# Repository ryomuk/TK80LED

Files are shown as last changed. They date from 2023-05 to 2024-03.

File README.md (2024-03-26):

# TK80LED
TK-80互換機(ZK-80P)用LED表示盤(TK-80 flavor LED board for ZK-80P)

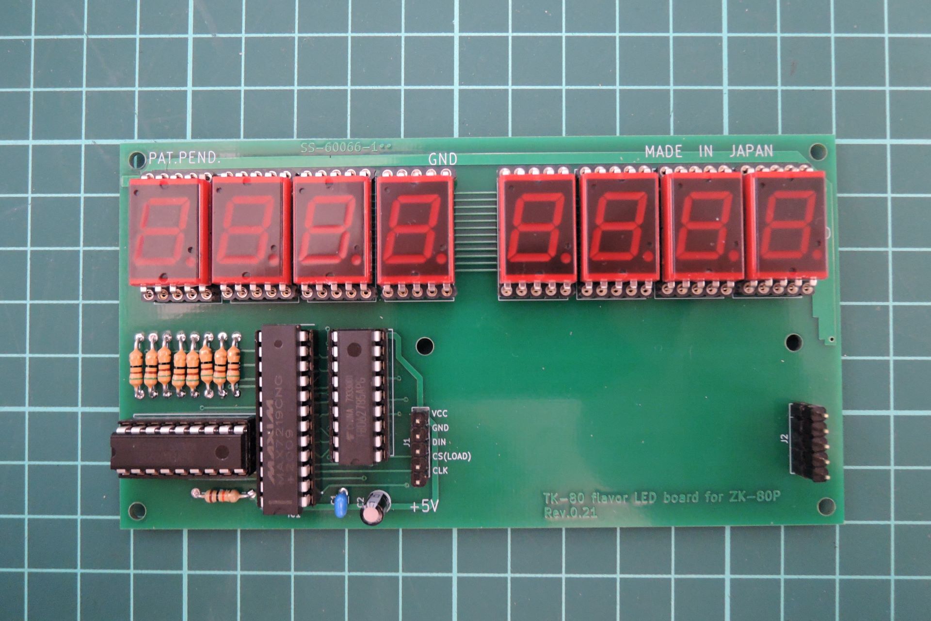
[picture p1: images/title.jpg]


## 概要
オレンジピコショップで売られているTK-80互換機(ZK-80 ポケット(ZK-80P))用の表示盤
「TK-80 flavor LED board for ZK-80P」です．

オリジナルのキットの表示がTK-80っぽくなかったので，SN713を使って本物っぽくしてみました．
ZK-80ポケット(ZK-80P)用です．ZK-80には対応していません．

私が勝手に作ったもので，ZK-80, ZK-80Pの作者様やピコソフト様とは無関係です．

## 基板
配線パターン，LED配置，シルクはかなり実機に似せたこだわりの作り(笑)になっています．
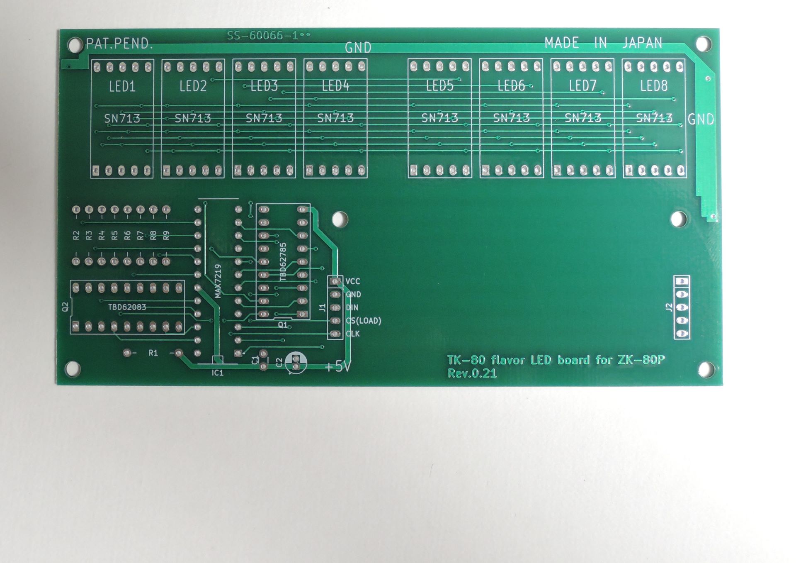
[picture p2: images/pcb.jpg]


## ファームウェア書き換えについて
ZK-80PはMAX7219の輝度の設定値が小さいので，そのままの設定でSN713を駆動するとかなり暗いです．
明るくするためには，ZK-80Pのファームウェアを書き換えが必要です．
ファームウェアの書き換えについては下記のブログをご参照下さい．

ファームウェア書き換え後
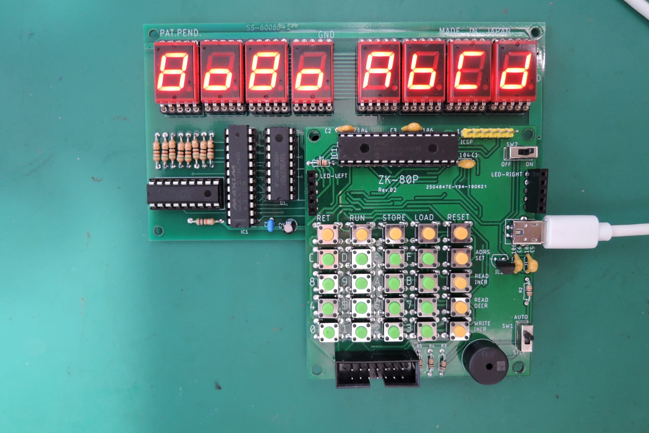
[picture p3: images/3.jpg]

実機との比較
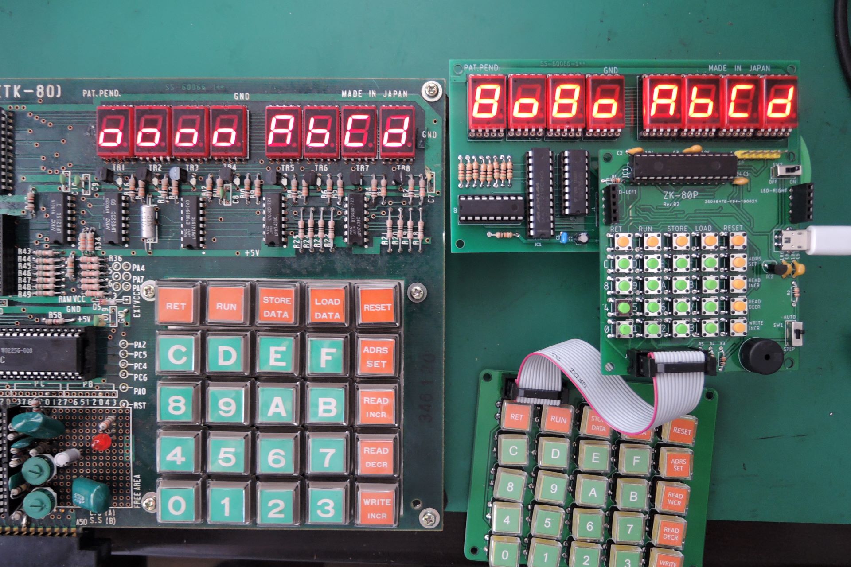
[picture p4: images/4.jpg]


ファームウェア書き換え前
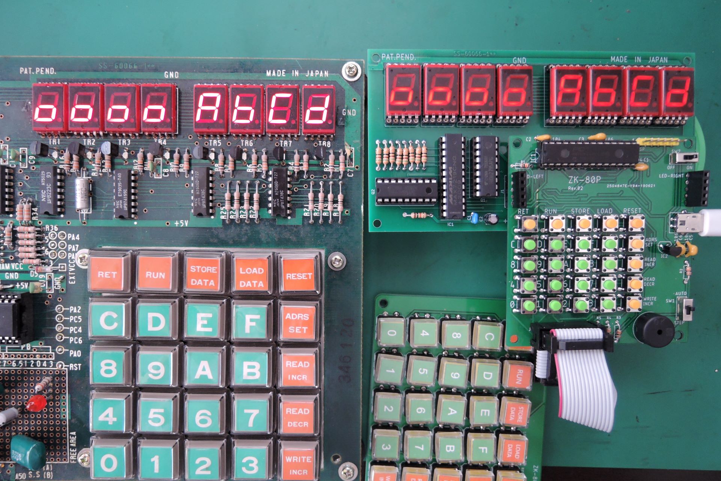
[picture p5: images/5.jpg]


## 関連ブログ
 - [ZK-80(TK-80互換機)のLED改装](https://blog.goo.ne.jp/tk-80/e/5548a42761d789a6131d8d7753d236a3)

## 免責事項
- 本機によってZK-80Pに不具合等が発生しても一切関知しません．

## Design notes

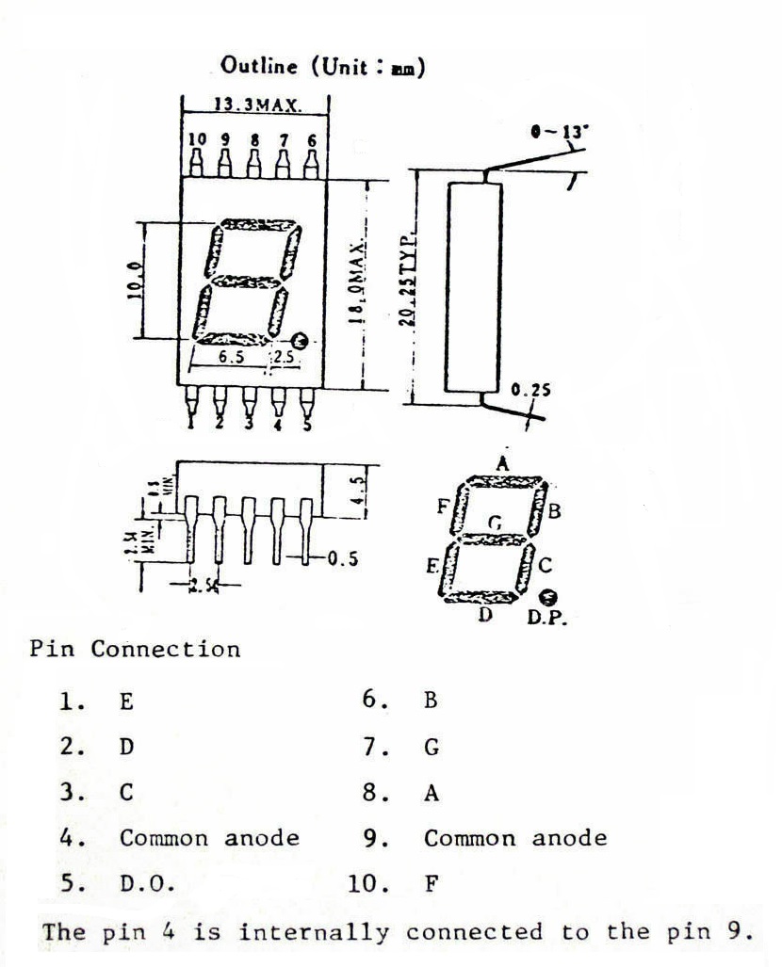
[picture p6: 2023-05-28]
hardware/rev0.21/SN713datasheet.jpg

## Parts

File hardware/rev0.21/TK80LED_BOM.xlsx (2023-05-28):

部品表
Item | Qty | Reference(s) | Value | 備考
1 | 1 | C1 | 0.1uF
2 | 1 | C2 | 10uF
3 | 1 | IC1 | MAX7219CNG
4 | 2 | J1, J2 | Conn_01x05 | ピンヘッダ、ピンソケット等、接続方法にあわせて任意
5 | 8 | LED1, LED2, LED3, LED4, LED5, LED6, LED7, LED8 | SN713B | SN713A(入手困難)でも可
6 | 1 | Q1 | TBD62785APG
7 | 1 | Q2 | TBD62083APG
8 | 1 | R1 | 10kΩ, 1/4W
9 | 8 | R2, R3, R4, R5, R6, R7, R8, R9 | 51Ω, 1/4W

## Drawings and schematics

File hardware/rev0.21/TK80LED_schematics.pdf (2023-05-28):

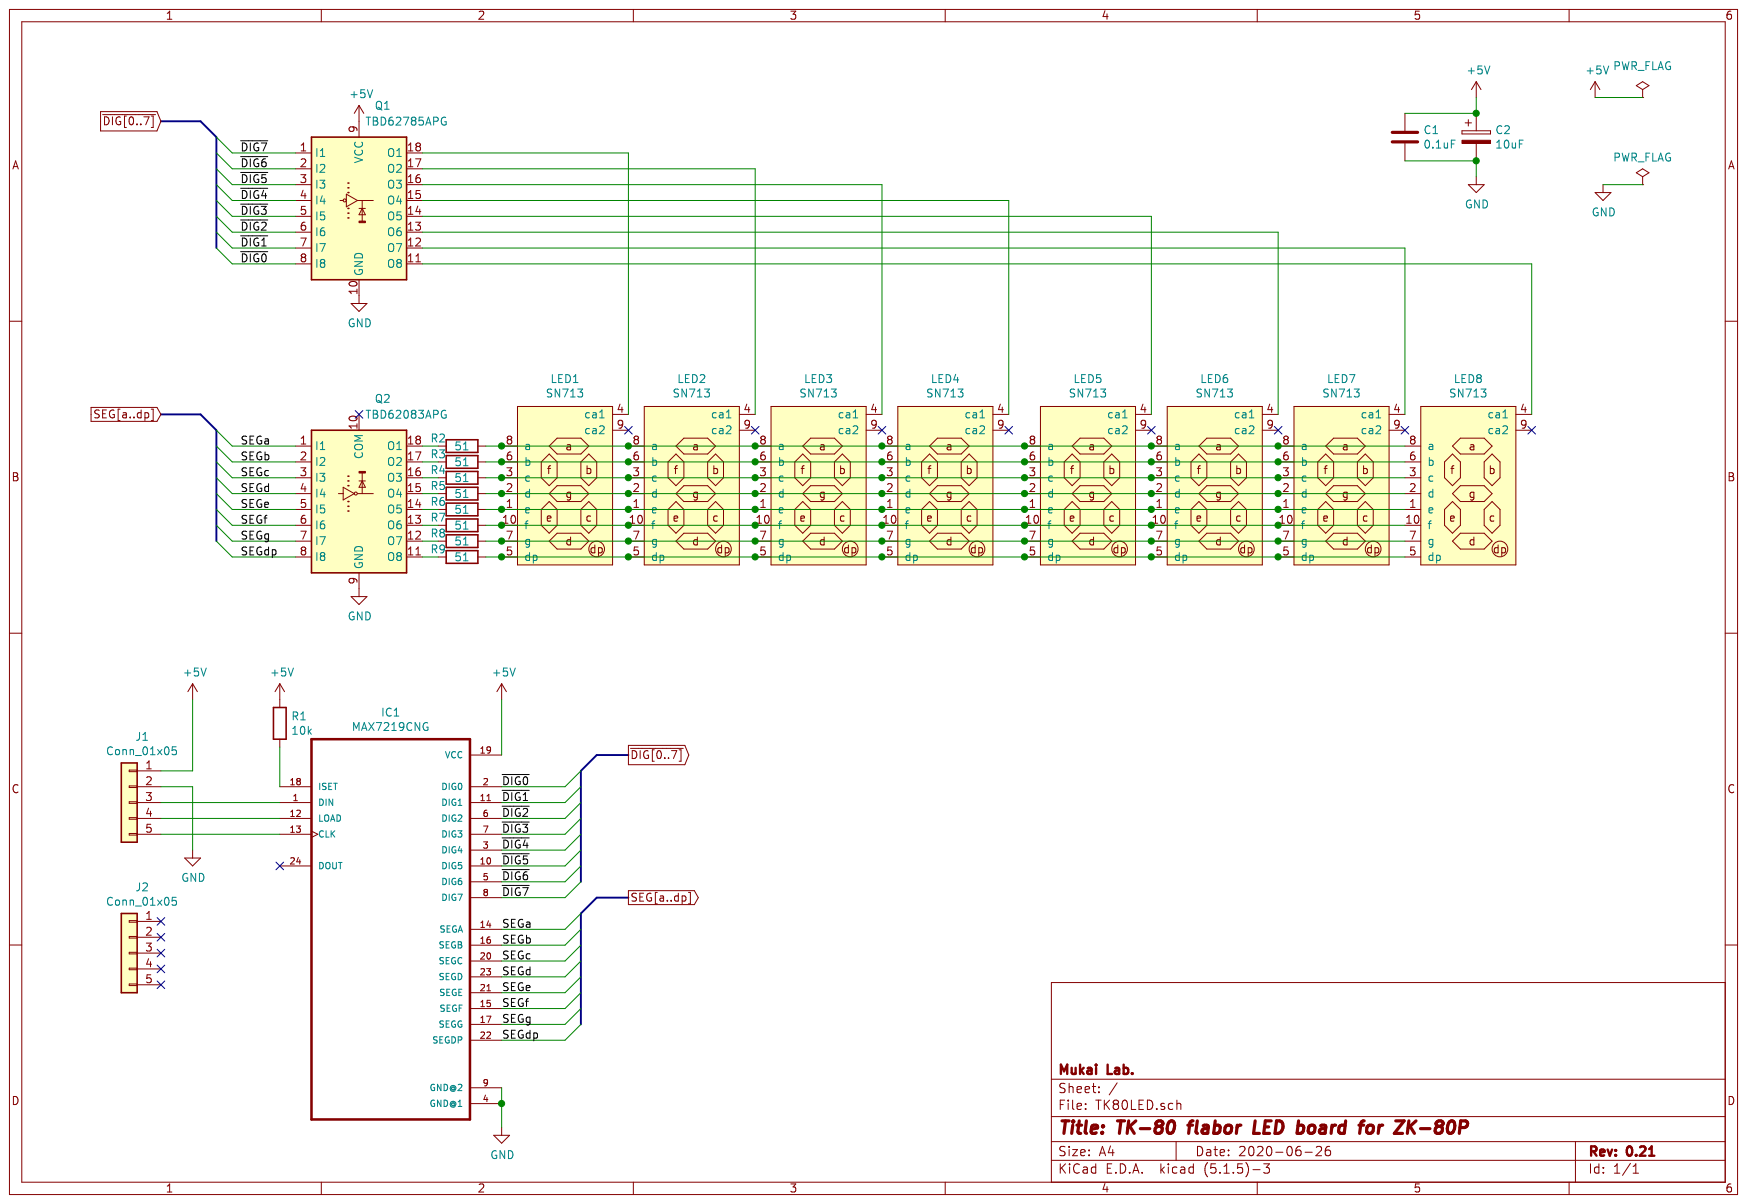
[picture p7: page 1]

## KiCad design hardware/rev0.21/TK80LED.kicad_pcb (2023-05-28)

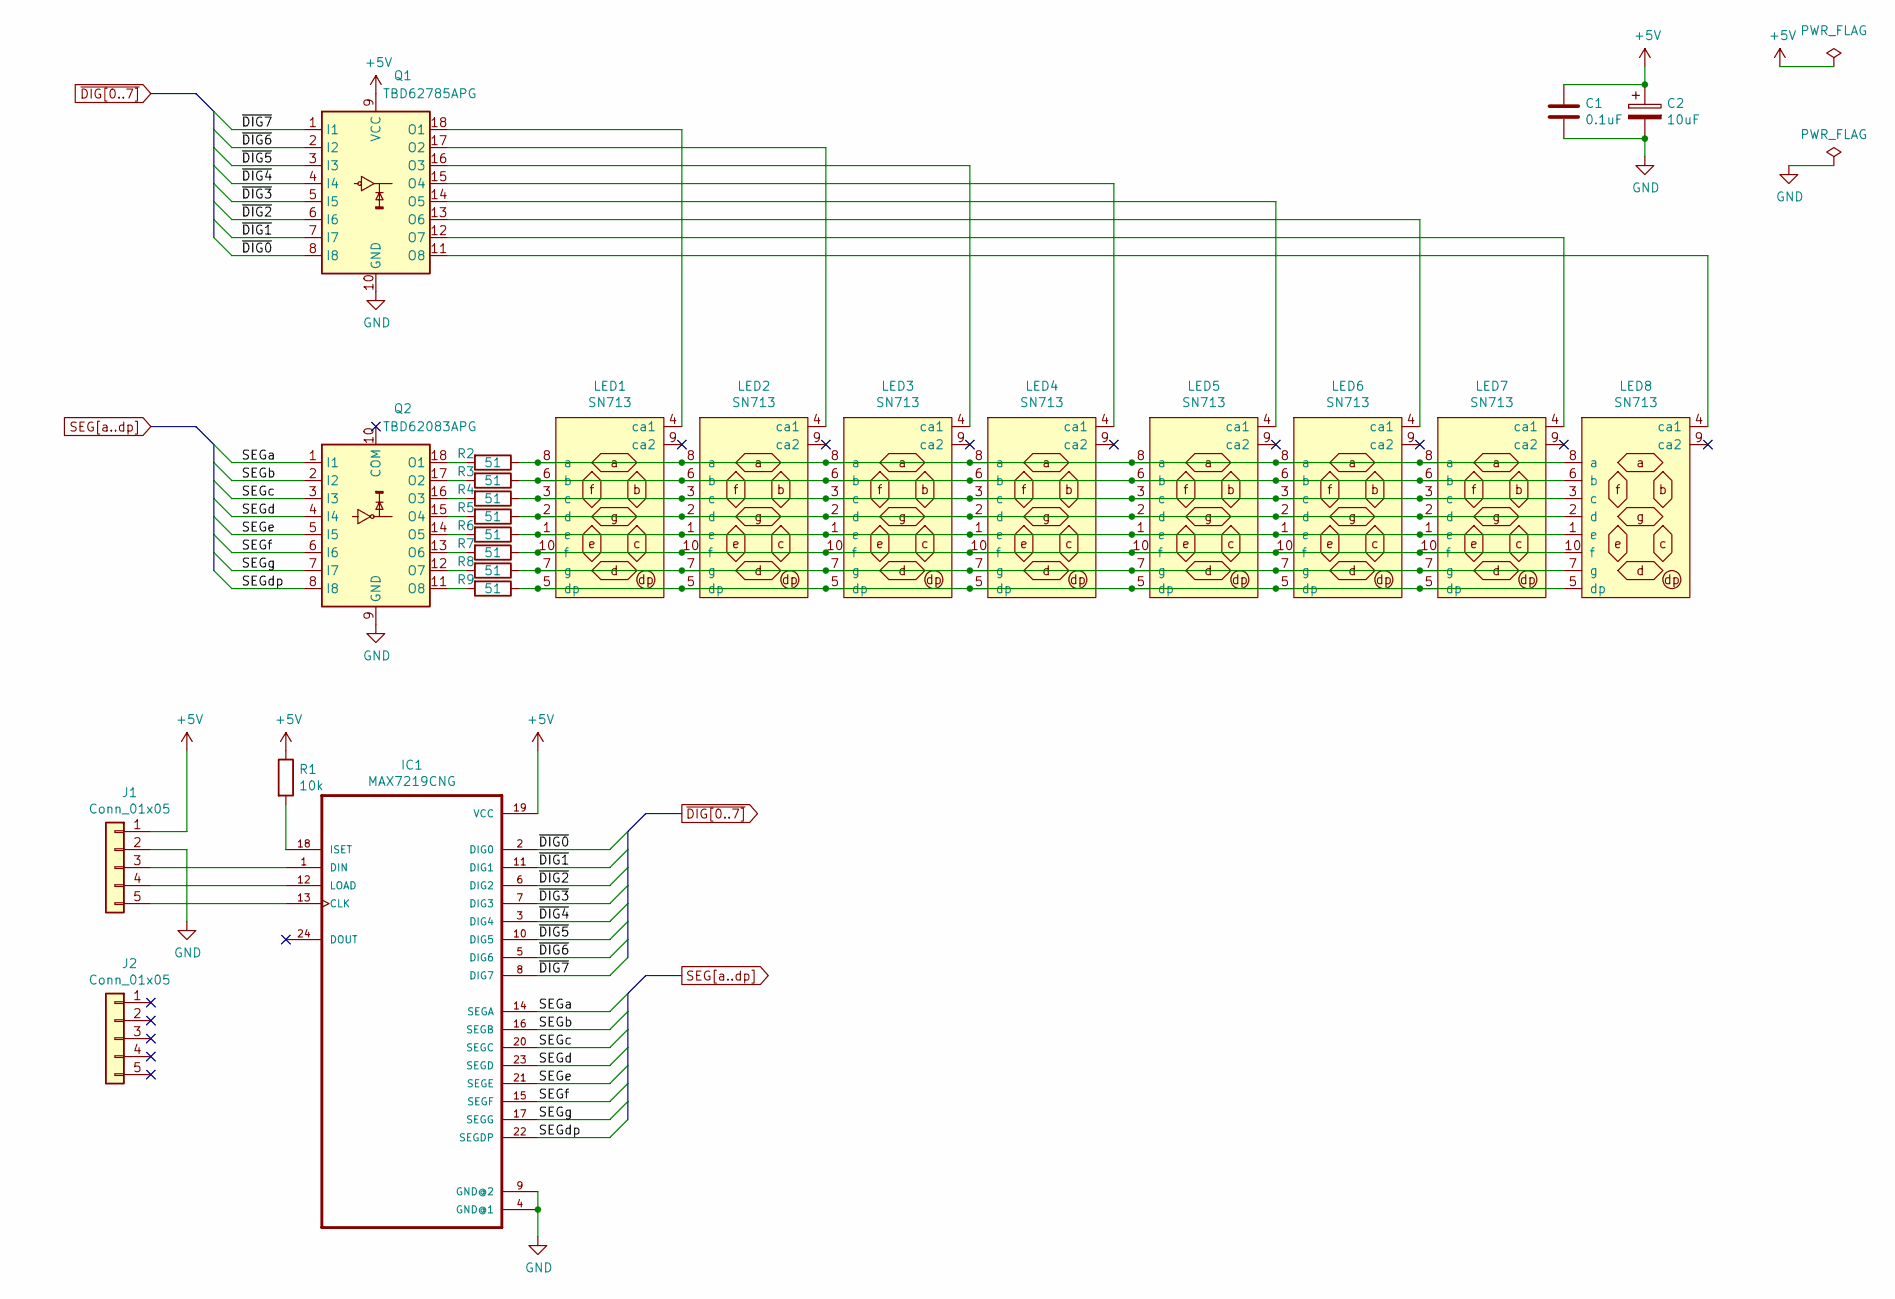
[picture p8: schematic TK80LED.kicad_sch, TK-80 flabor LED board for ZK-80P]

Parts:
C1: 0.1uF; C_Disc_D3.0mm_W1.6mm_P2.50mm
C2: 10uF; CP_Radial_D4.0mm_P1.50mm
IC1: MAX7219CNG; DIP794W47P254L3213H457Q24
J1, J2: Conn_01x05; SIP-5
LED1, LED2, LED3, LED4, LED5, LED6, LED7, LED8: SN713; DIP-10_800_ELL_LED
Q1: TBD62785APG; DIP-18_296_ELL
Q2: TBD62083APG; DIP-18_296_ELL
R1: 10k; R_Axial_DIN0207_L6.3mm_D2.5mm_P10.16mm_Horizontal
R2, R3, R4, R5, R6, R7, R8, R9: 51; R_Axial_DIN0207_L6.3mm_D2.5mm_P10.16mm_Horizontal

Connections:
+5V: C1.1, C2.1, IC1.19 (VCC), J1.1, Q1.9 (VCC), R1.1
/SEGa: IC1.14 (SEGA), Q2.1 (I1)
/SEGb: IC1.16 (SEGB), Q2.2 (I2)
/SEGc: IC1.20 (SEGC), Q2.3 (I3)
/SEGd: IC1.23 (SEGD), Q2.4 (I4)
/SEGdp: IC1.22 (SEGDP), Q2.8 (I8)
/SEGe: IC1.21 (SEGE), Q2.5 (I5)
/SEGf: IC1.15 (SEGF), Q2.6 (I6)
/SEGg: IC1.17 (SEGG), Q2.7 (I7)
GND: C1.2, C2.2, IC1.4 (GND@1), IC1.9 (GND@2), J1.2, Q1.10 (GND), Q2.9 (GND)
unnamed: IC1.1 (DIN), J1.3
unnamed: IC1.12 (LOAD), J1.4
unnamed: IC1.13 (CLK), J1.5
unnamed: IC1.18 (ISET), R1.2
unnamed: LED1.1 (e), LED2.1 (e), LED3.1 (e), LED4.1 (e), LED5.1 (e), LED6.1 (e), LED7.1 (e), LED8.1 (e), R6.1
unnamed: LED1.2 (d), LED2.2 (d), LED3.2 (d), LED4.2 (d), LED5.2 (d), LED6.2 (d), LED7.2 (d), LED8.2 (d), R5.1
unnamed: LED1.3 (c), LED2.3 (c), LED3.3 (c), LED4.3 (c), LED5.3 (c), LED6.3 (c), LED7.3 (c), LED8.3 (c), R4.1
unnamed: LED1.4 (ca1), Q1.18 (O1)
unnamed: LED1.5 (dp), LED2.5 (dp), LED3.5 (dp), LED4.5 (dp), LED5.5 (dp), LED6.5 (dp), LED7.5 (dp), LED8.5 (dp), R9.1
unnamed: LED1.6 (b), LED2.6 (b), LED3.6 (b), LED4.6 (b), LED5.6 (b), LED6.6 (b), LED7.6 (b), LED8.6 (b), R3.1
unnamed: LED1.7 (g), LED2.7 (g), LED3.7 (g), LED4.7 (g), LED5.7 (g), LED6.7 (g), LED7.7 (g), LED8.7 (g), R8.1
unnamed: LED1.8 (a), LED2.8 (a), LED3.8 (a), LED4.8 (a), LED5.8 (a), LED6.8 (a), LED7.8 (a), LED8.8 (a), R2.1
unnamed: LED1.10 (f), LED2.10 (f), LED3.10 (f), LED4.10 (f), LED5.10 (f), LED6.10 (f), LED7.10 (f), LED8.10 (f), R7.1
unnamed: LED2.4 (ca1), Q1.17 (O2)
unnamed: LED3.4 (ca1), Q1.16 (O3)
unnamed: LED4.4 (ca1), Q1.15 (O4)
unnamed: LED5.4 (ca1), Q1.14 (O5)
unnamed: LED6.4 (ca1), Q1.13 (O6)
unnamed: LED7.4 (ca1), Q1.12 (O7)
unnamed: LED8.4 (ca1), Q1.11 (O8)
unnamed: Q2.11 (O8), R9.2
unnamed: Q2.12 (O7), R8.2
unnamed: Q2.13 (O6), R7.2
unnamed: Q2.14 (O5), R6.2
unnamed: Q2.15 (O4), R5.2
unnamed: Q2.16 (O3), R4.2
unnamed: Q2.17 (O2), R3.2
unnamed: Q2.18 (O1), R2.2
~DIG0: IC1.2 (DIG0), Q1.8 (I8)
~DIG1: IC1.11 (DIG1), Q1.7 (I7)
~DIG2: IC1.6 (DIG2), Q1.6 (I6)
~DIG3: IC1.7 (DIG3), Q1.5 (I5)
~DIG4: IC1.3 (DIG4), Q1.4 (I4)
~DIG5: IC1.10 (DIG5), Q1.3 (I3)
~DIG6: IC1.5 (DIG6), Q1.2 (I2)
~DIG7: IC1.8 (DIG7), Q1.1 (I1)

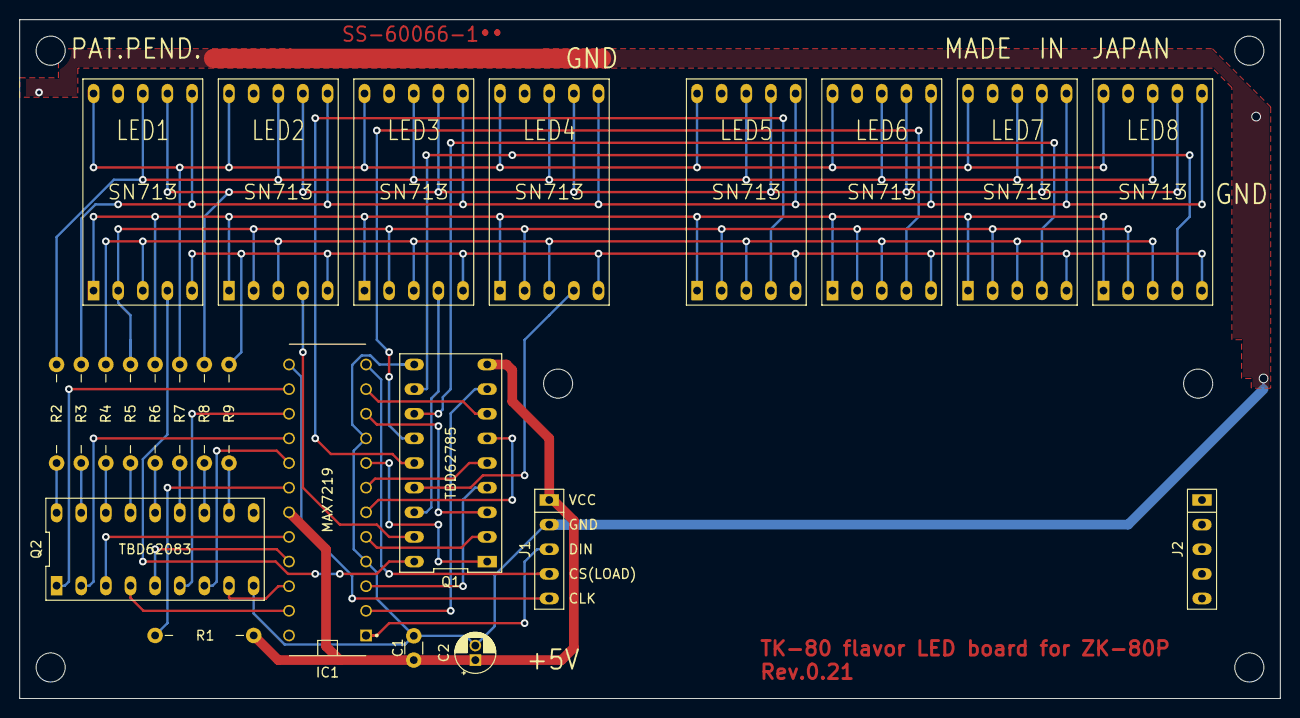
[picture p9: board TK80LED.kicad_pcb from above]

Board: 2 copper layers, 130.0 x 70.0 mm, 30 parts (0 on the bottom side), 46 nets.

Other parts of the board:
REF1, REF2, REF3, REF4, REF5, REF6: MountingHole_3mm

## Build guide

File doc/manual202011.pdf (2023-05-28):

TK-80互換機(ZK-80ポケット)用LED表示盤キット 説明書

部品表
部品番号 | 数量 | 品目 | 型番等 | 備考
LED1～8 | 8 | 7セグメントLED | NEC SN713B
IC1 | 1 | LEDドライバIC | Maxim MAX7219 | 24pin narrow DIP(CNG+又はENG+ )
Q1 | 1 | トランジスタアレイ | Toshiba TBD62785 | 18pin DIP(APG)
Q2 | 1 | トランジスタアレイ | Toshiba TBD62083 | 18pin DIP(APG)
R1 | 1 | 抵抗 | 10kΩ | カラーコード: 茶黒橙金
R2～R9 | 8 | 抵抗 | 51Ω | カラーコード: 緑茶黒金
C1 | 1 | コンデンサ | 0.1μF | 印字:104
C2 | 1 | コンデンサ | 10μF | 極性あり
| 1 | プリント基板 | | TK-80 flavor LED board Rev.0.21
| 2 | ピンソケット | 40pin | LED1～8用。5pin×16個に分割して使用。
| 1 | ICソケット | 24pin | IC1用
| 2 | ICソケット | 18pin | Q1, Q2用
| 2 | ピンヘッダー | 5pin | ZK-80Pとの接続用。
| 2 | ピンソケット | 5pin | ZK-80Pとの接続用。

【組み立ての際の注意事項等】
・ソケット類は必須ではありませんので、必要に応じてご使用下さい。 ・LEDソケット用は、40ピンソケットを5Pづつ分割して使用します。気をつけて分割しないと綺 麗に割れないのでご注意下さい。(割るのに失敗した場合に備えて予備を少しだけ同梱しまし た。) ・C2は極性があります。シルク印刷でご確認下さい。

・Q1, Q2は型番をよくご確認の上実装して下さい。
・Q1, Q2, IC1の実装方向は、シルク印刷、1番ピンを示す四角いパッドでご確認下さい。

【ZK-80Pとの接続について】
オリジナルのMAX7219LEDモジュールと置き換えると、本モジュールをZK-80Pの上にマウントす ることになりますが、それだと電源スイッチやキースイッチ等が隠れてしまうので、ZK-80Pを本 モジュールの上にマウントすることを想定しています。もしくは、ケーブルで接続してもいいか もしれません。
⾧短2種類のピンヘッダー、ピンソケットを同梱していますので、お好きな方をご使用下さい。

【ZK-80Pのファームウェア修正について】
ZK-80PはMAX7219の輝度の設定値が小さいので、そのままの設定でSN713を駆動するとかなり暗 いです。明るくするためには、ZK-80Pのファームウェアを書き換えが必要です。ファームウェア の書き換えについては下記のブログの2020-01-05の記事「ZK-80(TK-80互換機)のLED改装」をご参 照下さい。
https://blog.goo.ne.jp/tk-80
